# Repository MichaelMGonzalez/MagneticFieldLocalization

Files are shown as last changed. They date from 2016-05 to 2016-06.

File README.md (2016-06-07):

# MagneticFieldLocalization
The itensities of an indoor magnetic field may be used to aid localization of a mobile robot. This repository contains all the required files for an experiment to map and localize this field.

| Task | Status | Priority |Comments | Next Steps
| ---  | --- | --- | --- | ---
| **3D CAD**
| 3D Phone Model | In-Progress | Medium | Test Model Printed | Re-print larger model
| 3D IR Wheel Encoder Model | In-Progress | Medium | Test Model Printed | Re-print larger model
| ---
| **Circuit**
| Make Board | ORDERED | HIGHEST | Waiting on Phone Model Test/ Schematic Verification | Solder
| Make Schemematic | Made Encoder| HIGHEST | Symbol/Phone Model Symbol/Voltage Divider | . | Label Resistor Values/Verify
| ---
| **Arduino Code**
| Main ino program | Started | High | . | Draft
| Program Wheel Encoder | General Logic Drafted | Medium | Started to write header file| Test on hardware
| Differential Drive  | Classes made | Medium | Started to write header file| Test on hardware
| PID Controller | Classes made | Low | . | Test on hardware
| Serial Communicator | Generation framework made | Medium | Shared Message Framework created | Lower baud rate
| ---
| **Android Code**
| GUI | Using sample code | Medium | . | Commit/Draft user flow chart
| Magnometer Sensor API | In-Progress | High | . | Read through API's
| Serial Communicator | External API's tested | High | Shared Message Framework created | Lower baud rate
| Localizer | Not Started | Very High | Depends on most everything else before we can begin | Finish everything else
| Network Module | Not Started | Medium/Low | It would be really nice to have some way to control the robot from a computer | ?
| ---
| **Python Data Viewers**
| Histogram Plotter | Made Script to plot velocities | Low | . | Generalize?
| Scatter Plot | Made Script to plot sensor voltages | Low | . | Generalize?
| ---

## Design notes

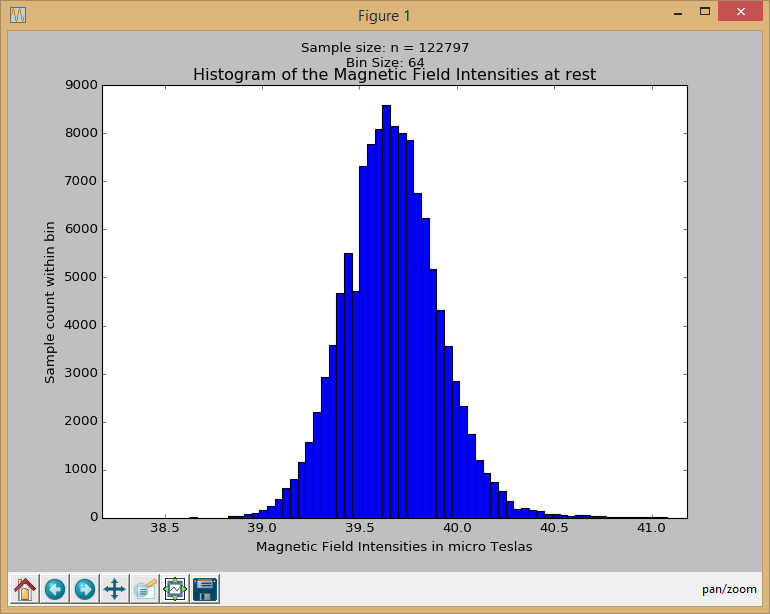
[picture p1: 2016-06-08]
MagneticFieldData/MagneticFieldHistogram.png

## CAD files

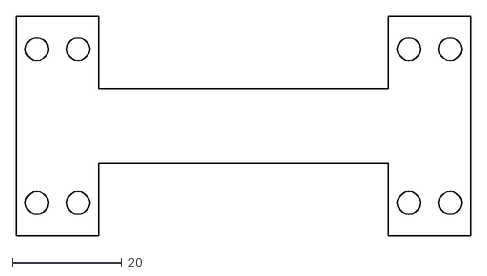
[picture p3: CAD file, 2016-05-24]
CAD/3D_Parts/PhoneMount.dxf
82.8 x 40.0

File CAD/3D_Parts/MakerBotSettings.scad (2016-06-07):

// Printer settings
extruder_width = 0.4;
global_correction = 0.04 + 1*extruder_width;

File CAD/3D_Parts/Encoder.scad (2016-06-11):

include <MakerBotSettings.scad>
use <MotorModel.scad>;
printer_error = global_correction;

sensor_width  = 6.10 + printer_error; //~6.11
sensor_height = 4.39 + printer_error; //~4.40
sensor_depth  = 4.65 + printer_error;  //~4.66

bracket_width = sensor_width / 4;

encasing_scale = 1.3;
encasing_height = sensor_height * encasing_scale;
encasing_width = sensor_width * encasing_scale;
encasing_depth = sensor_depth * encasing_scale;

rotate( 0, [1,0,0] )
FullEncoder_IR();



module FullEncoder_IR() {
    union() {
        SensorBox(1);
		  translate( [0,-3,-21.8])
		  	MotorCase(error=printer_error);
		  translate( [0,-.5*encasing_height, -.8 * encasing_depth] )
//rotate(90, [1,0,0] )
cube( [sensor_width,sensor_width*.8,4], center = true );

translate([0,-.845*sensor_height, (.9-encasing_scale)]) rotate(180) SensorBox(1);
    }
}
module SensorBox(size=1) {
    difference() {
        Sensor(encasing_scale*size);
        translate( [ 0, 1, 0 ] )
        Sensor();
        translate( [0,-2,0] )
        Sensor(.7*size);
    }
}
module Sensor(s=1) { 
	cube( [s*sensor_width, s*sensor_height, s*sensor_depth ], center = true );
}

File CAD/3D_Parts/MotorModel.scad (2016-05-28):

include <MakerBotSettings.scad>
printer_error = .03;

motor_width  = 42.18;
motor_depth  = 13.90;
motor_height = 22.81;

casing_scale  = 1.1;
casing_width  = casing_scale * motor_width;
casing_height = casing_scale * casing_scale * motor_height;
casing_depth  = 6;


MotorCase(error=printer_error);
//Motor();

module MotorCase(error=0) {

	difference() {
		cube( [casing_width+error, casing_depth+error, casing_height+error ], center=true );
		Motor(error=error);
		translate( [0,0,-1*casing_height/2] )
		Motor(error=error,size=.74);	
        Cutout();
		
	}



}

module Cutout(error=0) {
	translate( [0,0, motor_height/2] )
		cube([ casing_width,.7, 1], center=true );

		translate( [0,casing_depth/-2, (casing_height/casing_scale)/2] )
		cube([ motor_width,5, 1], center=true );

		translate( [0,casing_depth/2, (casing_height/casing_scale)/2] )
		cube([ motor_width,5, 1], center=true );
		
		// Side decals
      for(i = [motor_height/-2 : 2 : motor_height/2 ])
		translate([0,0,i])
		cube([ casing_width*2+error, .7, 1 ],center=true );
}

module Motor(error=0,size=1) {
    cube( [size*motor_width+error, size*motor_depth+error, size*motor_height+error ], center=true );
}

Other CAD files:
CAD/3D_Parts/LBracket.scad
CAD/3D_Parts/PhoneMount.scad
CAD/3D_Parts/PhoneOutline.scad
CAD/3D_Parts/Phone_Test.scad
CAD/3D_Parts/ScrewMount.scad
CAD/3D_Parts/ScrewMountTest.scad

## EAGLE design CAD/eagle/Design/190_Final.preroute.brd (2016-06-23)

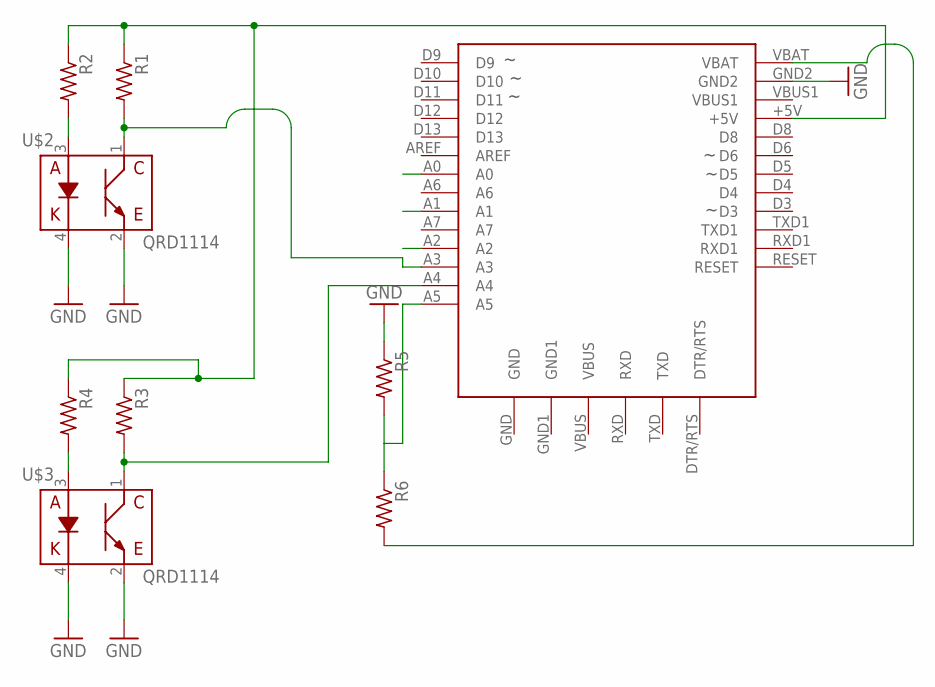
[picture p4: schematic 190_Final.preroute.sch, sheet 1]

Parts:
R1, R2, R3, R4, R5, R6: R-US_0204/7; 0204/7
U1_0_BRAIN: ADAFRUIT-PRO-TRINKET-5V-BOB; ADAFRUIT-PRO-TRINKET-5V
U$2, U$3: QRD1114

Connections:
+5V_0_BRAIN: R1.1, R2.1, R3.1, R4.1, U1_0_BRAIN.+5V; also elsewhere on the board
A0_0_BRAIN: U1_0_BRAIN.A0; also elsewhere on the board
A1_0_BRAIN: U1_0_BRAIN.A1; also elsewhere on the board
A2_0_BRAIN: U1_0_BRAIN.A2; also elsewhere on the board
A3_0_BRAIN: R1.2, U1_0_BRAIN.A3, U$2.1 (E)
A4_0_BRAIN: R3.2, U1_0_BRAIN.A4, U$3.1 (E)
A5_0_BRAIN: R5.2, R6.1, U1_0_BRAIN.A5
A6_0_BRAIN: U1_0_BRAIN.A6
A7_0_BRAIN: U1_0_BRAIN.A7
AREF_0_BRAIN: U1_0_BRAIN.AREF
D3_0_BRAIN: U1_0_BRAIN.D3; also elsewhere on the board
D4_0_BRAIN: U1_0_BRAIN.D4; also elsewhere on the board
D5_0_BRAIN: U1_0_BRAIN.D5; also elsewhere on the board
D6_0_BRAIN: U1_0_BRAIN.D6; also elsewhere on the board
D8_0_BRAIN: U1_0_BRAIN.D8; also elsewhere on the board
D9_0_BRAIN: U1_0_BRAIN.D9; also elsewhere on the board
D10_0_BRAIN: U1_0_BRAIN.D10; also elsewhere on the board
D11_0_BRAIN: U1_0_BRAIN.D11; also elsewhere on the board
D12_0_BRAIN: U1_0_BRAIN.D12; also elsewhere on the board
D13_0_BRAIN: U1_0_BRAIN.D13; also elsewhere on the board
DTR/RTS_0_BRAIN: U1_0_BRAIN.DTR/RTS
GND_0_BRAIN: R5.1, U1_0_BRAIN.GND, U1_0_BRAIN.GND1, U1_0_BRAIN.GND2, U$2.2 (C), U$2.4 (K), U$3.2 (C), U$3.4 (K); also elsewhere on the board
unnamed: R2.2, U$2.3 (A)
unnamed: R4.2, U$3.3 (A)
POS_1_BATTERY: R6.2, U1_0_BRAIN.VBAT; also elsewhere on the board
RESET_0_BRAIN: U1_0_BRAIN.RESET
RXD1_0_BRAIN: U1_0_BRAIN.RXD1
RXD_0_BRAIN: U1_0_BRAIN.RXD
TXD1_0_BRAIN: U1_0_BRAIN.TXD1
TXD_0_BRAIN: U1_0_BRAIN.TXD
VBUS1_0_BRAIN: U1_0_BRAIN.VBUS1
VBUS_0_BRAIN: U1_0_BRAIN.VBUS

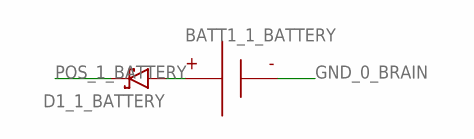
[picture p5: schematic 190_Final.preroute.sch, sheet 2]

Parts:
BATT1_1_BATTERY: BATTERY-9V-VERTICAL; BATTERY_9V_KEYSTONE_968
D1_1_BATTERY: RESOLVED-DIODE-SCHOTTKY_TH-DO-41-AND-DO-204AL; DIOAD1125W78L520D270_HS; MPN 1N5817

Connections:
GND_0_BRAIN: BATT1_1_BATTERY.N; also elsewhere on the board
unnamed: BATT1_1_BATTERY.P, D1_1_BATTERY.A
POS_1_BATTERY: D1_1_BATTERY.C; also elsewhere on the board

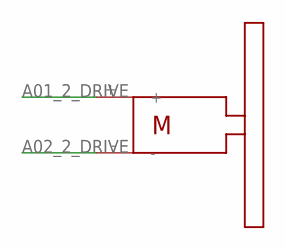
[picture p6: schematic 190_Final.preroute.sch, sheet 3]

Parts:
R_2_DRIVE: SOLARBOTICS_GM2; SOLARBOTICS_G2

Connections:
A01_2_DRIVE: R_2_DRIVE.+; also elsewhere on the board
A02_2_DRIVE: R_2_DRIVE.-; also elsewhere on the board

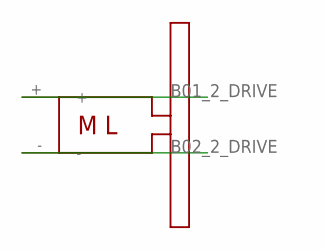
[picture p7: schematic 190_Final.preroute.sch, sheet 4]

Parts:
L_2_DRIVE: SOLARBOTICS_GM2_LEFT; SOLARBOTICS_G2_LEFT

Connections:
B01_2_DRIVE: L_2_DRIVE.+; also elsewhere on the board
B02_2_DRIVE: L_2_DRIVE.-; also elsewhere on the board

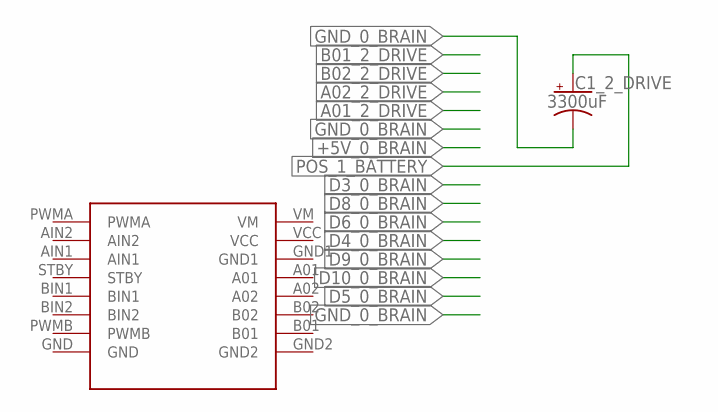
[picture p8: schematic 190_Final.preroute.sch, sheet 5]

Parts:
C1_2_DRIVE: 3300uF; CAPPRD750W80D1600H2200P; MPN ECA-1EM332
DRVR_2_DRIVE: SPARKFUN_DUAL_MOTOR_DRIVER-BOB; SPARKFUN_DUAL_MOTOR_DRIVER

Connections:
+5V_0_BRAIN: DRVR_2_DRIVE.VCC; also elsewhere on the board
A01_2_DRIVE: DRVR_2_DRIVE.A01; also elsewhere on the board
A02_2_DRIVE: DRVR_2_DRIVE.A02; also elsewhere on the board
B01_2_DRIVE: DRVR_2_DRIVE.B01; also elsewhere on the board
B02_2_DRIVE: DRVR_2_DRIVE.B02; also elsewhere on the board
D3_0_BRAIN: DRVR_2_DRIVE.PWMA; also elsewhere on the board
D4_0_BRAIN: DRVR_2_DRIVE.STBY; also elsewhere on the board
D5_0_BRAIN: DRVR_2_DRIVE.PWMB; also elsewhere on the board
D6_0_BRAIN: DRVR_2_DRIVE.AIN1; also elsewhere on the board
D8_0_BRAIN: DRVR_2_DRIVE.AIN2; also elsewhere on the board
D9_0_BRAIN: DRVR_2_DRIVE.BIN1; also elsewhere on the board
D10_0_BRAIN: DRVR_2_DRIVE.BIN2; also elsewhere on the board
GND_0_BRAIN: C1_2_DRIVE.2 (-), DRVR_2_DRIVE.GND, DRVR_2_DRIVE.GND1, DRVR_2_DRIVE.GND2; also elsewhere on the board
POS_1_BATTERY: C1_2_DRIVE.1 (+), DRVR_2_DRIVE.VM; also elsewhere on the board

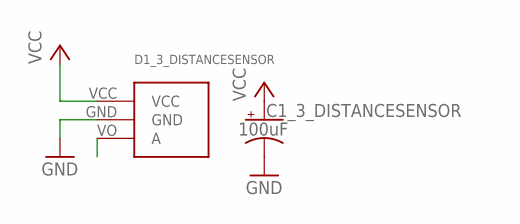
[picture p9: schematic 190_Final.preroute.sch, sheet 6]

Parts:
C1_3_DISTANCESENSOR: 100uF; CAPPRD250W80D630H1220P; MPN ECA-1EM101
D1_3_DISTANCESENSOR: ANALOG_DISTANCE_SENSOR-GLUE; ANALOG_DISTANCE_SENSOR_GLUE_MOUNT

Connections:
+5V_0_BRAIN: C1_3_DISTANCESENSOR.1 (+), D1_3_DISTANCESENSOR.VCC; also elsewhere on the board
A0_0_BRAIN: D1_3_DISTANCESENSOR.VO (A); also elsewhere on the board
GND_0_BRAIN: C1_3_DISTANCESENSOR.2 (-), D1_3_DISTANCESENSOR.GND; also elsewhere on the board

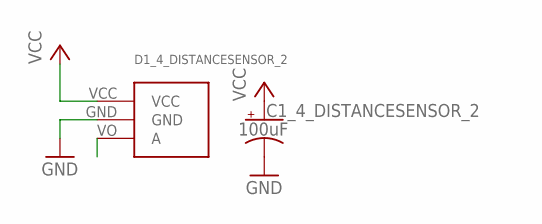
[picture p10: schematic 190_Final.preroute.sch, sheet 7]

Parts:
C1_4_DISTANCESENSOR_2: 100uF; CAPPRD250W80D630H1220P; MPN ECA-1EM101
D1_4_DISTANCESENSOR_2: ANALOG_DISTANCE_SENSOR-GLUE; ANALOG_DISTANCE_SENSOR_GLUE_MOUNT

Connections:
+5V_0_BRAIN: C1_4_DISTANCESENSOR_2.1 (+), D1_4_DISTANCESENSOR_2.VCC; also elsewhere on the board
A1_0_BRAIN: D1_4_DISTANCESENSOR_2.VO (A); also elsewhere on the board
GND_0_BRAIN: C1_4_DISTANCESENSOR_2.2 (-), D1_4_DISTANCESENSOR_2.GND; also elsewhere on the board

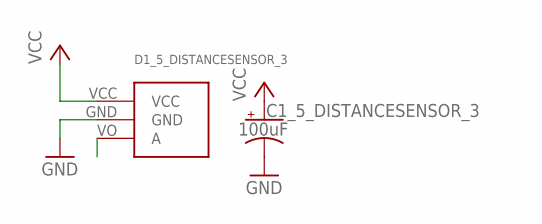
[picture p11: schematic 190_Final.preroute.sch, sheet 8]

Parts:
C1_5_DISTANCESENSOR_3: 100uF; CAPPRD250W80D630H1220P; MPN ECA-1EM101
D1_5_DISTANCESENSOR_3: ANALOG_DISTANCE_SENSOR-GLUE; ANALOG_DISTANCE_SENSOR_GLUE_MOUNT

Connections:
+5V_0_BRAIN: C1_5_DISTANCESENSOR_3.1 (+), D1_5_DISTANCESENSOR_3.VCC; also elsewhere on the board
A2_0_BRAIN: D1_5_DISTANCESENSOR_3.VO (A); also elsewhere on the board
GND_0_BRAIN: C1_5_DISTANCESENSOR_3.2 (-), D1_5_DISTANCESENSOR_3.GND; also elsewhere on the board

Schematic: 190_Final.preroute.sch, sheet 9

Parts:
U1_6_CASTER: CASTERADAFRUIT-3/4IN; ADAFRUIT-3/4IN-CASTER

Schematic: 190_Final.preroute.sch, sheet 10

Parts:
U1_7_CASTER_2: CASTERADAFRUIT-3/4IN; ADAFRUIT-3/4IN-CASTER

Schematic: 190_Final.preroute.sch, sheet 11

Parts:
LED1_8_LED: LED5MM
R1_8_LED: 330; RESAD770W45L370D210_HS; MPN CFR-12JB-52-330R

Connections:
D11_0_BRAIN: LED1_8_LED.A; also elsewhere on the board
GND_0_BRAIN: R1_8_LED.2; also elsewhere on the board
unnamed: LED1_8_LED.K (C), R1_8_LED.1

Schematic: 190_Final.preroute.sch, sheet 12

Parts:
LED1_9_LED_2: LED5MM
R1_9_LED_2: 330; RESAD770W45L370D210_HS; MPN CFR-12JB-52-330R

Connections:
D12_0_BRAIN: LED1_9_LED_2.A; also elsewhere on the board
GND_0_BRAIN: R1_9_LED_2.2; also elsewhere on the board
unnamed: LED1_9_LED_2.K (C), R1_9_LED_2.1

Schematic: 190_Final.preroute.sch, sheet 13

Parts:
B1_10_BUTTON: BUTTON-TACTILE-ROUND; BUTTON-TACTILE-ROUND-ADAFRUIT1009

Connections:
D13_0_BRAIN: B1_10_BUTTON.P; also elsewhere on the board
GND_0_BRAIN: B1_10_BUTTON.S; also elsewhere on the board

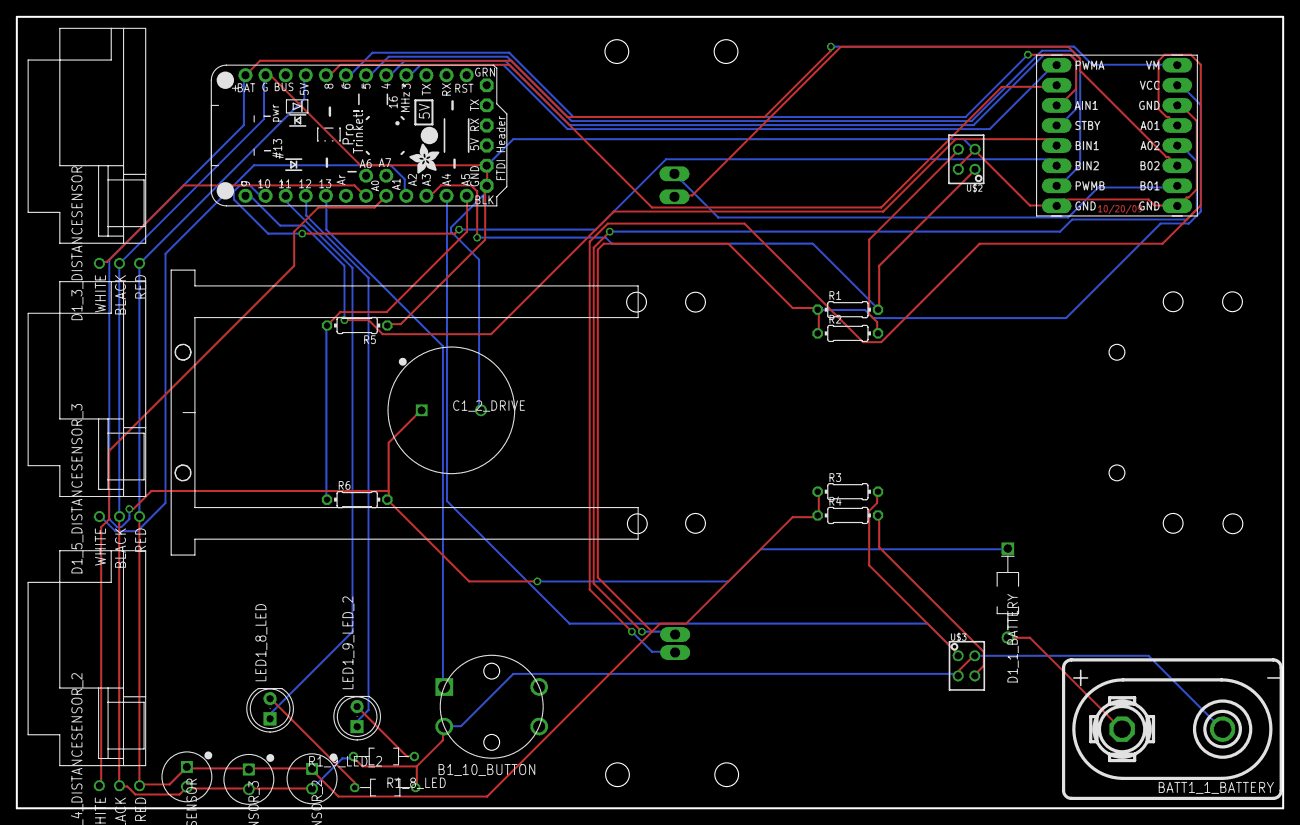
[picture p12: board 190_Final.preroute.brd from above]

Board: 2 copper layers, 160.0 x 100.0 mm, 30 parts (0 on the bottom side), 28 nets.

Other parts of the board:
U$1: PHONE_STAND
U$4: IRSTAND

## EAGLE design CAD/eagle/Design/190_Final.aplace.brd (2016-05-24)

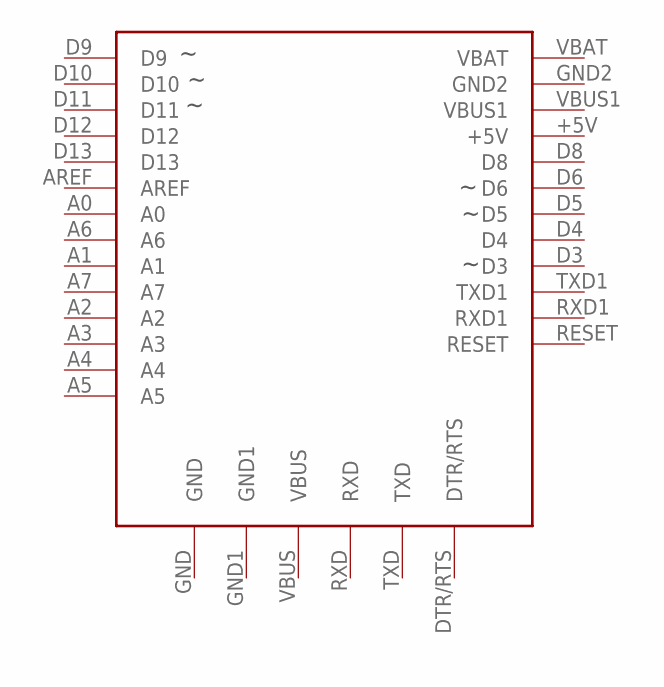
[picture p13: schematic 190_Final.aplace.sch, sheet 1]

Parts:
U1_0_brain: ADAFRUIT-PRO-TRINKET-5V-BOB; ADAFRUIT-PRO-TRINKET-5V

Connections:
+5V_0_brain: U1_0_brain.+5V; also elsewhere on the board
A0_0_brain: U1_0_brain.A0; also elsewhere on the board
A1_0_brain: U1_0_brain.A1; also elsewhere on the board
A2_0_brain: U1_0_brain.A2; also elsewhere on the board
A3_0_brain: U1_0_brain.A3
A4_0_brain: U1_0_brain.A4
A5_0_brain: U1_0_brain.A5
A6_0_brain: U1_0_brain.A6
A7_0_brain: U1_0_brain.A7
AREF_0_brain: U1_0_brain.AREF
D3_0_brain: U1_0_brain.D3; also elsewhere on the board
D4_0_brain: U1_0_brain.D4; also elsewhere on the board
D5_0_brain: U1_0_brain.D5; also elsewhere on the board
D6_0_brain: U1_0_brain.D6; also elsewhere on the board
D8_0_brain: U1_0_brain.D8; also elsewhere on the board
D9_0_brain: U1_0_brain.D9; also elsewhere on the board
D10_0_brain: U1_0_brain.D10; also elsewhere on the board
D11_0_brain: U1_0_brain.D11; also elsewhere on the board
D12_0_brain: U1_0_brain.D12; also elsewhere on the board
D13_0_brain: U1_0_brain.D13; also elsewhere on the board
DTR/RTS_0_brain: U1_0_brain.DTR/RTS
GND_0_brain: U1_0_brain.GND, U1_0_brain.GND1, U1_0_brain.GND2; also elsewhere on the board
POS_1_battery: U1_0_brain.VBAT; also elsewhere on the board
RESET_0_brain: U1_0_brain.RESET
RXD1_0_brain: U1_0_brain.RXD1
RXD_0_brain: U1_0_brain.RXD
TXD1_0_brain: U1_0_brain.TXD1
TXD_0_brain: U1_0_brain.TXD
VBUS1_0_brain: U1_0_brain.VBUS1
VBUS_0_brain: U1_0_brain.VBUS

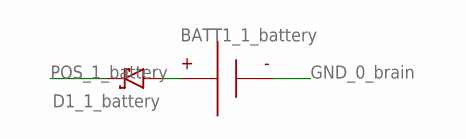
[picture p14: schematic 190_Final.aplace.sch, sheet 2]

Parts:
BATT1_1_battery: BATTERY-9V-VERTICAL; BATTERY_9V_KEYSTONE_968
D1_1_battery: RESOLVED-DIODE-SCHOTTKY_TH-DO-41-AND-DO-204AL; DIOAD1125W78L520D270_HS; MPN 1N5817

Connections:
GND_0_brain: BATT1_1_battery.N; also elsewhere on the board
unnamed: BATT1_1_battery.P, D1_1_battery.A
POS_1_battery: D1_1_battery.C; also elsewhere on the board

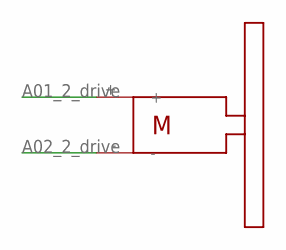
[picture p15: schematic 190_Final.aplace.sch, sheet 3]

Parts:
R_2_drive: SOLARBOTICS_GM2; SOLARBOTICS_G2

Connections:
A01_2_drive: R_2_drive.+; also elsewhere on the board
A02_2_drive: R_2_drive.-; also elsewhere on the board


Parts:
L_2_drive: SOLARBOTICS_GM2_LEFT; SOLARBOTICS_G2_LEFT

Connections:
B01_2_drive: L_2_drive.+; also elsewhere on the board
B02_2_drive: L_2_drive.-; also elsewhere on the board


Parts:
C1_2_drive: 3300uF; CAPPRD750W80D1600H2200P; MPN ECA-1EM332
DRVR_2_drive: SPARKFUN_DUAL_MOTOR_DRIVER-BOB; SPARKFUN_DUAL_MOTOR_DRIVER

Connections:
+5V_0_brain: DRVR_2_drive.VCC; also elsewhere on the board
A01_2_drive: DRVR_2_drive.A01; also elsewhere on the board
A02_2_drive: DRVR_2_drive.A02; also elsewhere on the board
B01_2_drive: DRVR_2_drive.B01; also elsewhere on the board
B02_2_drive: DRVR_2_drive.B02; also elsewhere on the board
D3_0_brain: DRVR_2_drive.PWMA; also elsewhere on the board
D4_0_brain: DRVR_2_drive.STBY; also elsewhere on the board
D5_0_brain: DRVR_2_drive.PWMB; also elsewhere on the board
D6_0_brain: DRVR_2_drive.AIN1; also elsewhere on the board
D8_0_brain: DRVR_2_drive.AIN2; also elsewhere on the board
D9_0_brain: DRVR_2_drive.BIN1; also elsewhere on the board
D10_0_brain: DRVR_2_drive.BIN2; also elsewhere on the board
GND_0_brain: C1_2_drive.2 (-), DRVR_2_drive.GND, DRVR_2_drive.GND1, DRVR_2_drive.GND2; also elsewhere on the board
POS_1_battery: C1_2_drive.1 (+), DRVR_2_drive.VM; also elsewhere on the board


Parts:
C1_3_distanceSensor: 100uF; CAPPRD250W80D630H1220P; MPN ECA-1EM101
D1_3_distanceSensor: ANALOG_DISTANCE_SENSOR-GLUE; ANALOG_DISTANCE_SENSOR_GLUE_MOUNT

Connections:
+5V_0_brain: C1_3_distanceSensor.1 (+), D1_3_distanceSensor.VCC; also elsewhere on the board
A0_0_brain: D1_3_distanceSensor.VO (A); also elsewhere on the board
GND_0_brain: C1_3_distanceSensor.2 (-), D1_3_distanceSensor.GND; also elsewhere on the board


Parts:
C1_4_distanceSensor_2: 100uF; CAPPRD250W80D630H1220P; MPN ECA-1EM101
D1_4_distanceSensor_2: ANALOG_DISTANCE_SENSOR-GLUE; ANALOG_DISTANCE_SENSOR_GLUE_MOUNT

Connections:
+5V_0_brain: C1_4_distanceSensor_2.1 (+), D1_4_distanceSensor_2.VCC; also elsewhere on the board
A1_0_brain: D1_4_distanceSensor_2.VO (A); also elsewhere on the board
GND_0_brain: C1_4_distanceSensor_2.2 (-), D1_4_distanceSensor_2.GND; also elsewhere on the board


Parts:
C1_5_distanceSensor_3: 100uF; CAPPRD250W80D630H1220P; MPN ECA-1EM101
D1_5_distanceSensor_3: ANALOG_DISTANCE_SENSOR-GLUE; ANALOG_DISTANCE_SENSOR_GLUE_MOUNT

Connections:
+5V_0_brain: C1_5_distanceSensor_3.1 (+), D1_5_distanceSensor_3.VCC; also elsewhere on the board
A2_0_brain: D1_5_distanceSensor_3.VO (A); also elsewhere on the board
GND_0_brain: C1_5_distanceSensor_3.2 (-), D1_5_distanceSensor_3.GND; also elsewhere on the board

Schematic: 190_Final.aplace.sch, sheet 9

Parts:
u1_6_caster: CASTERADAFRUIT-3/4IN; ADAFRUIT-3/4IN-CASTER

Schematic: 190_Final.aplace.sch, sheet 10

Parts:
u1_7_caster_2: CASTERADAFRUIT-3/4IN; ADAFRUIT-3/4IN-CASTER

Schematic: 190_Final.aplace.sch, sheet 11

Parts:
LED1_8_led: LED5MM
R1_8_led: 330; RESAD770W45L370D210_HS; MPN CFR-12JB-52-330R

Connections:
D11_0_brain: LED1_8_led.A; also elsewhere on the board
GND_0_brain: R1_8_led.2; also elsewhere on the board
unnamed: LED1_8_led.K (C), R1_8_led.1

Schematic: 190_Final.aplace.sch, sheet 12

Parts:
LED1_9_led_2: LED5MM
R1_9_led_2: 330; RESAD770W45L370D210_HS; MPN CFR-12JB-52-330R

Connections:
D12_0_brain: LED1_9_led_2.A; also elsewhere on the board
GND_0_brain: R1_9_led_2.2; also elsewhere on the board
unnamed: LED1_9_led_2.K (C), R1_9_led_2.1

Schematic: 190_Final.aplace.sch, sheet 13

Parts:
B1_10_button: BUTTON-TACTILE-ROUND; BUTTON-TACTILE-ROUND-ADAFRUIT1009

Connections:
D13_0_brain: B1_10_button.P; also elsewhere on the board
GND_0_brain: B1_10_button.S; also elsewhere on the board

Board: 2 copper layers, 20 parts (0 on the bottom side), 23 nets, no tracks yet.

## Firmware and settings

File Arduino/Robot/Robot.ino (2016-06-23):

/** ############################# Robot Name ############################## **\
|** ~~~~~~~~~~~~~~~~~~~~~~~~~~~~~~***********~~~~~~~~~~~~~~~~~~~~~~~~~~~~~~ **|
|** ~~~~~~~~~~~~~~~~~~~~~~~~~~~~~/           \~~~~~~~~~~~~~~~~~~~~~~~~~~~~~ **|
|** ============================{  MagneticFL }============================ **|
|** ~~~~~~~~~~~~~~~~~~~~~~~~~~~~~\           /~~~~~~~~~~~~~~~~~~~~~~~~~~~~~ **|
|** ~~~~~~~~~~~~~~~~~~~~~~~~~~~~~~***********~~~~~~~~~~~~~~~~~~~~~~~~~~~~~~ **|
\** #############################[[[[[^_^]]]]]############################# **/



/** ======================================================================= **\
|** ------------------------------ Libraries ------------------------------ **|
\** ======================================================================= **/

// Gadgetron Libraries
#include <MomentaryButton.h>
#include <PinChangeInt.h>
#include <Motor.h>
#include <Servo.h>
#include <ServoMotor.h>
#include <GadgetManager.h>
#include <LED.h>

// 190 Libraries
#include "robot.h"
#include "SerialMsgHeader.h"
#include <DifferentialDrive.h>
#include <PIDController.h>
#include <IRWheelEncoder.h>
#include "SimpleRobot_HLSM.hpp"

/** ======================================================================= **\
|** ---------------------------- Pin Constants ---------------------------- **|
\** ======================================================================= **/

#define MOTOR1_STBY 4
#define MOTOR1_PWMA 3
#define MOTOR1_AIN1 6
#define MOTOR1_AIN2 8
#define MOTOR1_PWMB 5
#define MOTOR1_BIN1 9
#define MOTOR1_BIN2 10
#define LED1_CONTROL 11
#define LED2_CONTROL 12
#define MOMENTARYBUTTON1_SENSE 13

#define DISTANCESENSOR1_A A0
#define DISTANCESENSOR2_A A1
#define DISTANCESENSOR3_A A2
#define ENCODER_LEFT A4
#define ENCODER_RIGHT A3

// State constants

#define MOVING 0
#define IDLE 1
#define TESTING 2

// State variables
uint8_t state = TESTING;

// Left Wheel's Angular Velocity
float l_a = 0;
// Right Wheel's Angular Velocity
float r_a = 0;
// Robot Velocities
float velocity = 0;
float angular_velocity = 0;

// Wheel Control values
float l_c = 0;
float r_c = 0;

// PID Values
float p = 1.2;
float d = 1.5;
/** ======================================================================= **\
|** ------------------------- Object Declarations ------------------------- **|
\** ======================================================================= **/

Motor motor(MOTOR1_STBY, MOTOR1_PWMA, MOTOR1_AIN1, MOTOR1_AIN2, MOTOR1_PWMB, MOTOR1_BIN1, MOTOR1_BIN2);
LED led1(LED1_CONTROL);
LED led2(LED2_CONTROL);
MomentaryButton button(MOMENTARYBUTTON1_SENSE);
DifferentialDrive ddController = DifferentialDrive(WHEEL_RADIUS, DISTANCE_BETWEEN_WHEELS);
IRWheelEncoder left_encoder = IRWheelEncoder(ENCODER_LEFT);
IRWheelEncoder right_encoder = IRWheelEncoder(ENCODER_RIGHT);

PIDController l_pid_controller = PIDController( p, 0, d);
PIDController r_pid_controller = PIDController( p, 0, d);
SimpleRobot_HLSM state_machine;


/** ======================================================================= **\
|** --------------------------- Setup Function ---------------------------- **|
|** %%%%%%%%%%%%%%%%%%%%%%%%%%%%%%%%%%%%%%%%%%%%%%%%%%%%%%%%%%%%%%%%%%%%%%% **|
|** ............................. Description ............................. **|
|** The setup() function runs --ONCE-- when the Arduino boots up. As the    **|
|** name implies, it's useful to add code that 'sets up' your Gadget to     **|
|** run correctly.                                                          **|
|** %%%%%%%%%%%%%%%%%%%%%%%%%%%%%%%%%%%%%%%%%%%%%%%%%%%%%%%%%%%%%%%%%%%%%%% **|
\** ======================================================================= **/

void setup() {
   motor.setup();
   led1.setup();
   led2.setup();
   button.setup();
   reset();
   // Setup differential drive
   ddController.velocity = .05f;
   // Setup PID controllers
   l_pid_controller.dest = ddController.get_wheel_angular_velocity( LEFT_WHEEL );
   r_pid_controller.dest = ddController.get_wheel_angular_velocity( RIGHT_WHEEL );
   Serial.begin(BAUD_RATE);
}

void reset() {
   // Setup encoders
   long t = micros();
   left_encoder.setup();
   left_encoder.set_thresholds(934, 915);
   right_encoder.setup();
   right_encoder.set_thresholds(1016, 992);
   l_pid_controller.setup( t );
   r_pid_controller.setup( t );
   l_a = 0;
   r_a = 0;
   velocity = 0;
   angular_velocity = 0;
   l_c = 0;
   r_c = 0;
}

/** ======================================================================= **\
|** ---------------------------- Loop Function ---------------------------- **|
|** %%%%%%%%%%%%%%%%%%%%%%%%%%%%%%%%%%%%%%%%%%%%%%%%%%%%%%%%%%%%%%%%%%%%%%% **|
|** ............................. Description ............................. **|
|** The loop() function runs continuously after the setup() function        **|
|** finishes and while the Arduino is running. In other words, this         **|
|** function is called repeatly over and over again when it reaches the     **|
|** end of the function. This function is where the majority of your        **|
|** program's logic should go.                                              **|
|** %%%%%%%%%%%%%%%%%%%%%%%%%%%%%%%%%%%%%%%%%%%%%%%%%%%%%%%%%%%%%%%%%%%%%%% **|
\** ======================================================================= **/

void loop() {
  //test_sensors(true);
  state_machine.run();
  //report_values();
  test_sensors(true);
}

void report_values() {
  
  //send_float( REPORTING_STATE, state );
  send_int(REPORTING_STATE, state);
  send_float( REPORTING_VELOCITY, velocity );
  send_float( REPORTING_ANGULAR_VELOCITY, angular_velocity);
  send_float( REPORTING_L_ANGULAR_VELOCITY, l_a );
  send_float( REPORTING_R_ANGULAR_VELOCITY, r_a );
  send_float( REPORTING_P, l_pid_controller.p );
  send_float( REPORTING_D, l_pid_controller.d );
  send_float( REPORTING_R_C_DEST, r_pid_controller.dest );
  send_float( REPORTING_L_C_DEST, l_pid_controller.dest);
  send_int(REPORTING_R_CONTROL, r_c );
  send_int(REPORTING_L_CONTROL, l_c );
}


void send_float( byte state, float f ) {
  Serial.write( state );
  byte * buf = (byte * ) &f;
  Serial.write( buf, 4 );
  Serial.write( MSG_SENT );
}

void send_int( byte state, int i ) {
  Serial.write( state );
  byte * buf = (byte * ) &i;
  Serial.write( buf, 2 );
  Serial.write( MSG_SENT );
}
bool is_msg_valid( ) {
  bool rv = Serial.peek() == (byte)MSG_SENT;
  return rv;
}
void serialEvent() {
 if( Serial.available() > 1) {
   byte msg = Serial.read();
   // Is the message a direct command?
   if( is_msg_valid() ) {
     switch( msg ) {
       case STOP:
         state_machine.state = IDLE;
         motor.stop();
         break;
       case MOVE_FORWARD:
         state_machine.state = TESTPID;
         reset();
         break;
     }
   }
   // Otherwise, this message should be trying to set some value
   // These point to where where we want to store the message
   float * f_ptr1 = 0;
   float * f_ptr2 = 0;
   int * i_ptr    = 0;
   delay(100);
   switch( msg ) {
     case SET_P:
       f_ptr1 = &l_pid_controller.p;
       f_ptr2 = &r_pid_controller.p;
       break; 
     case SET_D:
       f_ptr1 = &l_pid_controller.d;
       f_ptr2 = &r_pid_controller.d;
       break; 
   }
   // For floating point messages
   if( f_ptr1 ) {
     float f = 0;
     // This is an ugly hack to read a float from the serial port
     byte * f_ptr = (byte * )&f;
     for( int i = 0; i < 4; i++ ) f_ptr[i] = Serial.read();   
     if( is_msg_valid() ) {
       *f_ptr1 = f;
       if( f_ptr2 ) *f_ptr2 = f;
     }
   }
 }
}



void PIDLoop() {
  long t = micros();
  // Update encoders
  l_a = left_encoder.update( t );
  r_a = right_encoder.update( t);
  // Update Differential Drive Controller
  ddController.set_wheel_angular_velocity(RIGHT_WHEEL, r_a);
  ddController.set_wheel_angular_velocity(LEFT_WHEEL, l_a);
  // Update velocity beliefs
  velocity = ddController.get_linear_speed();
  angular_velocity = ddController.get_angular_velocity();

  l_c += l_pid_controller.update( l_a, t );
  r_c += r_pid_controller.update( r_a, t );
  l_c = clamp_control_sig( l_c );
  r_c = clamp_control_sig( r_c );
  if( l_c == 0 )
    left_encoder.setup();
  if( r_c == 0 )
    right_encoder.setup();
  set_left_power( l_c, 0 );
  set_right_power( r_c, 0 );
  //debug(t);


}


float clamp_control_sig( float sig ) {
  return min( 255, max( 0, sig ) );
}

void debug(long t) {
  Serial.print( "L Angular Velocity: " );
  Serial.print( l_a * WHEEL_RADIUS);
  Serial.print( "\t R Angular Velocity: " );
  Serial.print( r_a * WHEEL_RADIUS);
  Serial.print( "\tLinear Velocity: " );
  Serial.print( velocity );
  Serial.print( "\tAngular Velocity: " );
  Serial.print( angular_velocity );
  Serial.print("\tl_c: ");
  Serial.print(l_c);
  Serial.print("\tr_c: ");
  Serial.println(r_c);
}

void test_sensors(bool csv) {
  int val_1 = analogRead(ENCODER_LEFT);
  int val_2 = analogRead(ENCODER_RIGHT);
  String before_left  = csv ? ""   : "Left Sensor: ";
  String before_right = csv ? ", " : "\tRight Sensor: ";
  String before_time  = csv ? ", " : "\t Time Stamp: ";  
  Serial.print(before_left);
  Serial.print( val_1 );
  Serial.print(before_right);
  Serial.print( val_2 );
  Serial.print(before_time);
  Serial.println( micros() );

}

void set_right_power( int val, int dir ) {
  motor.move(1, val, dir);
}

void set_left_power( int val, int dir ) {
  motor.move(0, val, dir);
}

void set_power( int val, int dir ) {
  set_right_power( val, dir );
  set_left_power( val, dir );
}


void SimpleRobot_HLSM::ExecuteActionIdle() { }
void SimpleRobot_HLSM::ExecuteActionWaitForSecondPress() { }
void SimpleRobot_HLSM::ExecuteActionTestMotors() {
    motor.forward(100);
}
void SimpleRobot_HLSM::ExecuteActionTestPID() {
    PIDLoop();
}
bool SimpleRobot_HLSM::buttonPress() {
    return button.wasPressed(); 
}
bool SimpleRobot_HLSM::wait() {
    return timeEllapsed > 1000;
}

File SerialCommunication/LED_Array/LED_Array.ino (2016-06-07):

#include <Wire.h>
#include "Adafruit_LEDBackpack.h"
#include "Adafruit_GFX.h"
#include "SerialMsgHeader.h"

Adafruit_8x8matrix matrix = Adafruit_8x8matrix();

String toPrint = "0";
int p_idx = 0;
byte  draws [] = { 0, 0, 0, 0, 0, 0, 0, 0 };
void setup() {
  // put your setup code here, to run once:
  matrix.begin(0x70);
  Serial.begin(9600);
}

void loop() {
  // put your main code here, to run repeatedly:
  matrix.setRotation(3);

}

void serialEvent() {
    while(Serial.available()) {
    int readIn = Serial.read();
    toPrint = String(readIn);
    draws[p_idx] = readIn;
    p_idx = (p_idx+1)%8;
    matrix.clear();
    for( int i = 0; i < 8; i++ ) {
      drawByte(i, draws[i]);
    }
  }
  
  matrix.writeDisplay();
}


void drawByte( int x, byte b ) {
  for( int i = 0; i < 8; i++ ) {
    if( (1 << i) & b )
      matrix.drawPixel(x, i, 1 );
  }
 
}

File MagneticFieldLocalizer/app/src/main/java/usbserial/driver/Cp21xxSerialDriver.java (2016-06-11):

/* Copyright 2011-2013 Google Inc.
 * Copyright 2013 mike wakerly <opensource@hoho.com>
 *
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
 * Project home page: https://github.com/mik3y/usb-serial-for-android
 */

package usbserial.driver;

import android.hardware.usb.UsbConstants;
import android.hardware.usb.UsbDevice;
import android.hardware.usb.UsbDeviceConnection;
import android.hardware.usb.UsbEndpoint;
import android.hardware.usb.UsbInterface;
import android.util.Log;

import java.io.IOException;
import java.util.Collections;
import java.util.LinkedHashMap;
import java.util.List;
import java.util.Map;

public class Cp21xxSerialDriver implements UsbSerialDriver {

    private static final String TAG = Cp21xxSerialDriver.class.getSimpleName();

    private final UsbDevice mDevice;
    private final UsbSerialPort mPort;

    public Cp21xxSerialDriver(UsbDevice device) {
        mDevice = device;
        mPort = new Cp21xxSerialPort(mDevice, 0);
    }

    @Override
    public UsbDevice getDevice() {
        return mDevice;
    }

    @Override
    public List<UsbSerialPort> getPorts() {
        return Collections.singletonList(mPort);
    }

    public class Cp21xxSerialPort extends CommonUsbSerialPort {

        private static final int DEFAULT_BAUD_RATE = 9600;

        private static final int USB_WRITE_TIMEOUT_MILLIS = 5000;

        /*
         * Configuration Request Types
         */
        private static final int REQTYPE_HOST_TO_DEVICE = 0x41;

        /*
         * Configuration Request Codes
         */
        private static final int SILABSER_IFC_ENABLE_REQUEST_CODE = 0x00;
        private static final int SILABSER_SET_BAUDDIV_REQUEST_CODE = 0x01;
        private static final int SILABSER_SET_LINE_CTL_REQUEST_CODE = 0x03;
        private static final int SILABSER_SET_MHS_REQUEST_CODE = 0x07;
        private static final int SILABSER_SET_BAUDRATE = 0x1E;
        private static final int SILABSER_FLUSH_REQUEST_CODE = 0x12;

       private static final int FLUSH_READ_CODE = 0x0a;
       private static final int FLUSH_WRITE_CODE = 0x05;

        /*
         * SILABSER_IFC_ENABLE_REQUEST_CODE
         */
        private static final int UART_ENABLE = 0x0001;
        private static final int UART_DISABLE = 0x0000;

        /*
         * SILABSER_SET_BAUDDIV_REQUEST_CODE
         */
        private static final int BAUD_RATE_GEN_FREQ = 0x384000;

        /*
         * SILABSER_SET_MHS_REQUEST_CODE
         */
        private static final int MCR_DTR = 0x0001;
        private static final int MCR_RTS = 0x0002;
        private static final int MCR_ALL = 0x0003;

        private static final int CONTROL_WRITE_DTR = 0x0100;
        private static final int CONTROL_WRITE_RTS = 0x0200;

        private UsbEndpoint mReadEndpoint;
        private UsbEndpoint mWriteEndpoint;

        public Cp21xxSerialPort(UsbDevice device, int portNumber) {
            super(device, portNumber);
        }

        @Override
        public UsbSerialDriver getDriver() {
            return Cp21xxSerialDriver.this;
        }

        private int setConfigSingle(int request, int value) {
            return mConnection.controlTransfer(REQTYPE_HOST_TO_DEVICE, request, value,
                    0, null, 0, USB_WRITE_TIMEOUT_MILLIS);
        }

        @Override
        public void open(UsbDeviceConnection connection) throws IOException {
            if (mConnection != null) {
                throw new IOException("Already opened.");
            }

            mConnection = connection;
            boolean opened = false;
            try {
                for (int i = 0; i < mDevice.getInterfaceCount(); i++) {
                    UsbInterface usbIface = mDevice.getInterface(i);
                    if (mConnection.claimInterface(usbIface, true)) {
                        Log.d(TAG, "claimInterface " + i + " SUCCESS");
                    } else {
                        Log.d(TAG, "claimInterface " + i + " FAIL");
                    }
                }

                UsbInterface dataIface = mDevice.getInterface(mDevice.getInterfaceCount() - 1);
                for (int i = 0; i < dataIface.getEndpointCount(); i++) {
                    UsbEndpoint ep = dataIface.getEndpoint(i);
                    if (ep.getType() == UsbConstants.USB_ENDPOINT_XFER_BULK) {
                        if (ep.getDirection() == UsbConstants.USB_DIR_IN) {
                            mReadEndpoint = ep;
                        } else {
                            mWriteEndpoint = ep;
                        }
                    }
                }

                setConfigSingle(SILABSER_IFC_ENABLE_REQUEST_CODE, UART_ENABLE);
                setConfigSingle(SILABSER_SET_MHS_REQUEST_CODE, MCR_ALL | CONTROL_WRITE_DTR | CONTROL_WRITE_RTS);
                setConfigSingle(SILABSER_SET_BAUDDIV_REQUEST_CODE, BAUD_RATE_GEN_FREQ / DEFAULT_BAUD_RATE);
    //            setParameters(DEFAULT_BAUD_RATE, DEFAULT_DATA_BITS, DEFAULT_STOP_BITS, DEFAULT_PARITY);
                opened = true;
            } finally {
                if (!opened) {
                    try {
                        close();
                    } catch (IOException e) {
                        // Ignore IOExceptions during close()
                    }
                }
            }
        }

        @Override
        public void close() throws IOException {
            if (mConnection == null) {
                throw new IOException("Already closed");
            }
            try {
                setConfigSingle(SILABSER_IFC_ENABLE_REQUEST_CODE, UART_DISABLE);
                mConnection.close();
            } finally {
                mConnection = null;
            }
        }

        @Override
        public int read(byte[] dest, int timeoutMillis) throws IOException {
            final int numBytesRead;
            synchronized (mReadBufferLock) {
                int readAmt = Math.min(dest.length, mReadBuffer.length);
                numBytesRead = mConnection.bulkTransfer(mReadEndpoint, mReadBuffer, readAmt,
                        timeoutMillis);
                if (numBytesRead < 0) {
                    // This sucks: we get -1 on timeout, not 0 as preferred.
                    // We *should* use UsbRequest, except it has a bug/api oversight
                    // where there is no way to determine the number of bytes read
                    // in response :\ -- http://b.android.com/28023
                    return 0;
                }
                System.arraycopy(mReadBuffer, 0, dest, 0, numBytesRead);
            }
            return numBytesRead;
        }

        @Override
        public int write(byte[] src, int timeoutMillis) throws IOException {
            int offset = 0;

            while (offset < src.length) {
                final int writeLength;
                final int amtWritten;

                synchronized (mWriteBufferLock) {
                    final byte[] writeBuffer;
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

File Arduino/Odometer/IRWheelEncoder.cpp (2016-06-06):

#include "IRWheelEncoder.h"
IRWheelEncoder::IRWheelEncoder( uint8_t data_pin )  {
    pin = data_pin;
}

void IRWheelEncoder::setup() {
    last_scan = angular_velocity = 0;
    last_rising_edge = 0;
    waiting_for_edge = false;
}
float IRWheelEncoder::update(long curr_time) {
    int sensor_reading = analogRead(pin);
    if( sensor_reading > detection_threshold && waiting_for_edge ) {
        waiting_for_edge = false;   
        float delta_t = (curr_time - last_rising_edge) / 1000000.0;
        angular_velocity = 6.28318530718 / encoder_count / delta_t  ;
        last_rising_edge = curr_time;
    }
    else if( sensor_reading < fallen_threshold ) {
        waiting_for_edge = true;
    } 
    return angular_velocity;
}
void IRWheelEncoder::set_thresholds(int detection, int fallen) {
    detection_threshold = detection;
    fallen_threshold = fallen;
}

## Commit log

2016-05-18 commenting and generated dxf
    [PhoneMount.dxf, PhoneMount.scad]
2016-05-19 Made a folder for 3D parts, added encoder mount
    [Encoder.scad, Encoder.stl, PhoneMount.dxf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]
2016-05-20 made lbrackets
    [Encoder.scad, LBracket.scad]
2016-05-20 More openscad practice
    [MotorModel.scad, PhoneMount.scad, ScrewMountTest.scad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]
2016-05-20 3d motor bracket
    [Encoder.scad, Encoder.stl, MotorModel.scad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]
2016-05-20 removed some material from motor bracket
    [Encoder.scad, Encoder.stl, MotorModel.scad]
2016-05-20 removed old motor file
    [MotorModel.scad]
2016-05-24 Added design files
    [190_Final.aplace.brd, 190_Final.aplace.sch, 190_Final.g.brd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]
2016-05-24 updated phone case
    [Encoder.scad, Encoder.stl, MotorModel.scad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]
2016-05-24 caught a nasty electric bug
    [190_Final.preroute.brd, 190_Final.preroute.sch]
2016-05-24 more electrical bug catches
    [190_Final.preroute.brd, 190_Final.preroute.sch]
2016-05-24 Updated 3d phone bracket with more accurate extruder widths
    [PhoneMount.dxf, PhoneMount.scad]
2016-05-24 cleaning dirs, added gerbers
2016-05-24 Removed stl files, git ignores them now
    [Encoder.stl, MotorModel.stl, ScrewMountTest.stl]
2016-05-25 fixed pid bug, made tester/plotter
    [pid_sim.csv]
2016-05-26 made pid tests smoother
    [pid_sim.csv]
2016-05-26 refactored odometer, started making it into a class
    [6V_Period_Test.csv, 9V_Period_Test.csv, IR_Scanner_Data.csv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]
2016-05-26 updated PID sim to be more realistic with oscillation
2016-05-26 removed machine generated code
    [pid_sim.csv]
2016-05-26 gerbers updated, ready to fab
2016-05-28 made 3d models follow better OO design
    [Encoder.scad, MakerBotSettings.scad, MotorModel.scad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]
2016-05-28 Added LPKF build target for gerbers
    [190_Final.preroute_lpkf.brd]
2016-05-28 Updated design to use library updates
    [190_Final.postroute.brd, 190_Final.preroute.brd]
2016-05-28 Made PID simulator play nicer with git
2016-05-30 made lpkf design nicer for board mill
    [190_Final.preroute_lpkf.sch]
2016-05-31 Updated make files/lpkf board
    [190_Final.postroute.brd, shuriken.brd]
2016-06-01 massive refactor
    [190_Final.aplace.brd, 190_Final.aplace.sch, 190_Final.g.brd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]
2016-06-01 Defined encoder.cpp file
2016-06-05 Android
    Started Android - starting sensor API
2016-06-05 Differential drive can say what speed wheels should operate at
2016-06-05 Android magnetometer
    Is displaying Magnetometer values (magnitude of vector) from the
    calibrated magnetic filed sensor type. Starting Timer class.
2016-06-06 Android Timestamp
    Time and Magnetometer displays completed
2016-06-06 Refactored serial communicator, working on new odom models
    [6V_Dual_Wheel_Raw_Values.csv]
2016-06-06 John Doe is Ashley Perez
    My name is not John Doe. Timer class deleted, it ended up not being
    necessary.
2016-06-06 Arduino odometry library works!
    [6V_Dual_Wheel_Raw_Values_2.csv]
2016-06-06 PID Controller works!
2016-06-06 Android - Multiple files
    Creates a new file every time the start log button is pressed.
2016-06-07 PID seems relatively smooth, tons of serial debugging
    [PhoneMount.scad, PhoneOutline.scad]
2016-06-07 PID tests reproducable
    [p1.8d-.15.csv]
2016-06-07 PID Qlearning
2016-06-07 Serial communicator testing framework update
2016-06-07 Retook phone measurements, playing with makerbot settings
    [MakerBotSettings.scad, PhoneMount.scad, PhoneOutline.scad]
2016-06-08 fine tuned encoder thresholds
2016-06-08 MAGNETIC FIELD DATA
    [testrun1.csv, testrun2.csv, testrun3.csv]
2016-06-08 Accelerometer added
2016-06-08 Accel data not looking good, Mag looking fantastic
    [Accelerometer_Output32375263274683.csv, Accelerometer_Output4099260300961.csv, Magnetometer_Output32375263274683.csv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]
2016-06-11 overdue commits
    [Encoder.scad, PhoneMount.scad, pid_experiment.csv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]
2016-06-23 Added state machine to robot
    [190_Final.preroute.brd, OdomData.csv]
2016-06-24 Networking module, filtered accelerometer data
    [Accelerometer_Output_1466734126031.csv, Magnetometer_Output_1466734126026.csv]

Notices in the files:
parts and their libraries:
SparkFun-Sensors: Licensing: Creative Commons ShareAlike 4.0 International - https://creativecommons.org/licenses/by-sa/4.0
